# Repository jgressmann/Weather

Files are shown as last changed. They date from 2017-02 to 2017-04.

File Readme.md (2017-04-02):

# Weatherbug

A project to log temperature and relative humidity from battery powered sensor devices via radio.

## Overview

There are two parts to this project, a [Raspberry Pi](https://www.raspberrypi.org/) (RPI) which listens for sensor data and one or multiple sensor devices (henceforth simply called sensor or device).

The devices periodically send their sensor readings to the RPI by means of Nordic's [nRF24L01+](http://www.nordicsemi.com/eng/Products/2.4GHz-RF/nRF24L01) 2.4GHz radio (abbrev. to RF24 hereafter). Upon reception the sensor data is logged to file on the RPI.

### Mode of Operation

When a sensor device is first powered up it monitors the radio for a clock source. A clock source can be either the RPI which provides the master clock or another, properly synced, sensor device.

Once the device detects the clock it goes to sleep until the next _send_ interval. When the time comes the device is wakes up, takes an enviromental reading, and transmits the result to the RPI. At the end of this short _send period_ the sensor goes back to sleep.

### Network Topology

The sensor devices and the RPI form a mesh network. Routing in the network is done using the [B.A.T.M.A.N. protocol](https://tools.ietf.org/html/draft-wunderlich-openmesh-manet-routing-00). Sensor data is sent using a stripped down version of [TCP](https://tools.ietf.org/html/rfc793).

### Power supply and power consumption

Given the sensor device is designed to run on batteries it has to be operated on D.C. current with a max. input voltage of 6V. I have seen the device work correctly with input voltages as low as 3.5V.

Typical power consumption is around 25uA when the device is asleep and 15mA when active.

Under optimal conditions, the sensor can function on the battery for more than a year. However, failure to sync the device clock to the master clock cause it to enter a power consuming monitoring state. If this state persists AAA batteries are typically drained within days.

## Hardware

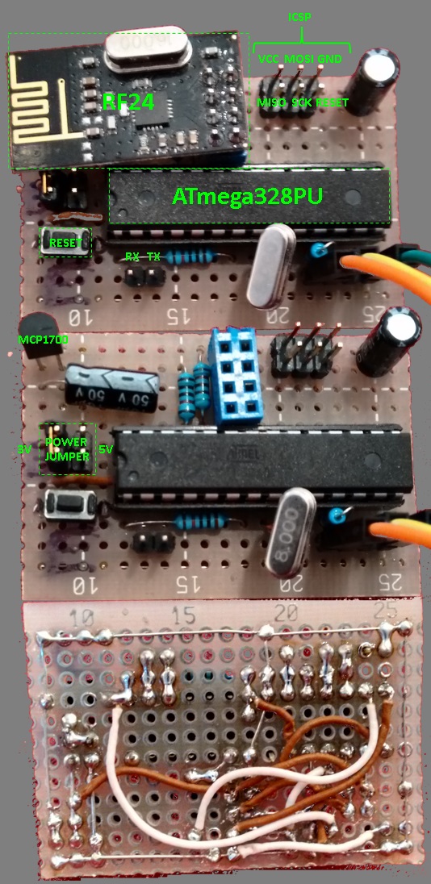
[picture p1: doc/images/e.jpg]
images of one of my devices


You will need to build the sensor devices. The parts are approx. EUR 10 per device. The circuit diagram is [here](doc/Weatherbug r1.2.fzz). I used the free and very nice [Frizzing](http://fritzing.org/) tool for the layout.

You'll also need to solder a capacitor to an RF24 radio chip and connect it to the RPI. Otherwise the radio will most likely not work due to power fluctuations. I use a 1uF capacitor which seems to do the trick.

Other than the device parts and some soldering skills you will need

* An avrdude compatible AVR programmer like [usbasp](http://www.fischl.de/usbasp/)
* a serial/COM port or an USB to serial adaptor to connect to the device UART
* a terminal program to communicate over the serial connection (I use picocom)

## Software

To build the device firmware you will need

* an Atmel (AVR) toolchain (libc, gcc, binutils) to build the firmware
* avrdude to upload the device firmware
* cmake 3.0 or better

If your are on Debian Linux

```
$ sudo apt-get install avrdude avr-libc gcc-avr binutils-avr
```

should get you set up.

### Building the device software

Get the sources, then run `cmake` on `src/avr/weatherbug` to configure the build environment. Next, run `make` (or whatever tool the cmake generated build instructions for) to build the firmware. Once the firmware image has been built, you can upload it to the device using `make flash_1.2` (assuming you use an usbasp compatible AVR programmer). Otherwise you will need to call `avrdude` with the right parameters for your device.

### Building the RPI software

Run `cmake` on `src/rpi` to set up the build, then run `make` followed by  `sudo DESTDIR=/path/to/install/to make install` to install the binaries

## Configuring the sensor device

Connect a power source to the device and hook up your serial cables. Make sure to connect the mass pin of the serial cable to the mass pin of the device, else you run danger of having a floating potential which might kill the device.

Also note that the serial communication will exhibit seemingly strange behavior or will simply cease to function if the cables are too long. I have worked with up to 30 cm, but as usual your mileage may vary.

The device is configured to 38400 baud with 8 data bits, 1 stop bit and no parity (8N1). Initiate a connection to the device using your favorite terminal program, e.g.

```
$ picocom -c -b 38400 --imap lfcrlf /dev/ttyUSB0
```

Once connected, hit the reset button. You should see the device greeting in the terminal program

```
Hello there!
This is Weatherbug version .....
```

### Service mode

During the first 10 seconds after power on or reset, the device is in bootstrap mode and will accept commands via the terminal. Type `?`+ENTER (the ? character followed by the ENTER key) to see a list of commands. Switch the device to service mode by typing `!serv`+ENTER.

Once in service mode you can configure the device using the various `!` commands. Type `?`+ENTER to see what's available.

Most settings are applied immediately and are not persisted so you can play around with them to try things out. If you muck up, simply reset the device and it will be back to its original configuration. To save your changes type `!cfst`+ENTER at the prompt.

When you are finished, type `!dflt`+ENTER to return to default mode.

#### Configuration caveats

1. The RF24 setup must be the _same_ for all devices _and_ the RPI in order to communicate via radio. Specifically
 * radio channel (defaults to 76)
 * CRC selection (defaults to 16 bit)
 * data rate (defaults to 2MBit)

 must be identical.

1. The payload size must be set to 32 bytes and the CRC to 16 bit on the RPI. These are the default settings for `rf24-packet-router` so everything _should_ work out of the box.

1. Each device as well as the RPI must have a _unique_ network id.

1. The network id `0xff` is reserved as the broadcast address.

## Start the monitoring software on the RPI

Start the packet router that will listen on the RF24 device

```
$ sudo rf24-packet-router --sleep 100 &
```

Then start the network which will handle the master clock generation, routing, and TCP.

```
$ rf24-network -i <network id> &
```

And finally start

```
$ rf24-tcp | tee sensor.log
```

to dump TCP messages to console and file.

## Troubleshooting

Let's face it. Things don't always work perfectly. For radio related issues there are two helper programs available to track down communication issues.

`rf24-ping` continously sends ping messages to the broadcast address.
`rf24-echo` prints whatever it receives to stdout/USART0.

## License

This software and documentation is available under the [MIT license](https://opensource.org/licenses/MIT)

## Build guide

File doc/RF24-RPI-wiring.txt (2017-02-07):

yellow RPI pin 26 CE
orange RPI pin 24 CSN
red    RPI pin 23 SCLK
black  RPI pin 21 MISO
brown  RPI pin 19 MOSI
gray   RPI pin 20 GND
white  RPI pin 17 3V3
       RPI pin 22 IRQ

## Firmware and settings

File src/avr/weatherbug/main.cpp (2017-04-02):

#include <avr/interrupt.h>
#include <avr/io.h>
#include <avr/eeprom.h>
#include <avr/power.h>
#include <avr/sleep.h>
#include <avr/pgmspace.h>
#include <avr/cpufunc.h>
#include <avr/signature.h>
#include <util/delay.h>
#include <util/atomic.h>

#include <stdio.h>
#include <string.h>
#include <stdlib.h>
#include <ctype.h>


#include "Watchdog.h"
#include "Timer.h"
#include "../../Misc.h"
#include "../Debug.h"
#include "../USART0.h"

#include "../SPI.h"
#include "../RF24.h"


#include "../../Batman.h"
#include "../../Network.h"
#include "../../Time.h"
#include "../../TCP.h"
#include "../DHT.h"

//#define ACTIVE_SLEEP
#define WATCHDOG_SLEEP
//#define TIMER2_SLEEP

#define TICKS_PER_MS (F_CPU/1000L)
#define TICKS_PER_US (F_CPU/1000000L)
// Atmel doc, p. 40
#define BOD_STARTUP_PENALTY_US 60


// Depends on fuses and if int. osc. or crystal, here we assume
// a full swing crystal thus 16K ticks
#define WDT_STARTUP_PENALTY_TICKS (UINT16_C(1)<<14)
#define WDT_STARTUP_PENALTY_MS (WDT_STARTUP_PENALTY_TICKS/TICKS_PER_MS)


#define NAME "Weatherbug"
#define VERSION_MAJOR 2
#define VERSION_MINOR 6
#define VERSION_PATCH 0
#define NODE_NAME_BUFFER_LENGTH 7
#define NODE_NAME_BUFFER_SIZE (NODE_NAME_BUFFER_LENGTH + 1)
static const char s_VersionString_P[] PROGMEM = NAME " " STRINGIFY(VERSION_MAJOR) "." STRINGIFY(VERSION_MINOR) "." STRINGIFY(VERSION_PATCH);
static const char Network_Address_Format_P[] PROGMEM = "%#02x\n";

/******************************************************************************/
/* Forward declerations                                                       */
/******************************************************************************/

#ifndef NDEBUG
extern "C" {
FILE* s_FILE_Debug NOINIT;
}
#endif

static void RF24_Init();
static uint16_t BATV_Read();
static inline uint16_t BATV_ToMilliVolt(uint16_t counts);

enum {
    MODE_STATE_UNINITIALIZED = -1,
    MODE_STATE_INITIAL = 0,
    MODE_STATE_SERVICE = 1,
    MODE_STATE_DEFAULT = 2,
};


struct ModeContext {
    uint32_t StartOfInterval;
    DHT_Context DHTContext;
    uint16_t Iterations;
    uint8_t USART0Index;
    int8_t CurrentState;
    uint8_t TargetState         : 2;
    uint8_t Enter               : 1;
    uint8_t Interval            : 1;
    uint8_t FeaturesReleased    : 1;
    uint8_t Run                 : 1;
    uint8_t DHTTries;
    uint8_t Temperature;
    uint8_t Humidity;
    char USART0Buffer[32];
};

static ModeContext s_ModeContext NOINIT;

#ifdef WATCHDOG_SLEEP
typedef struct {
    uint16_t CalibrationFactor;
    uint8_t Expired     : 1;
    uint8_t Calibrate   : 1;
} WatchdogData;

static volatile WatchdogData s_WATCH NOINIT;

#define WATCH_RequestCalibration() \
    s_WATCH.Calibrate = 1

#endif


/******************************************************************************/
/* Features (FEAT)                                                            */
/*                                                                            */
/* Reference counted access to device features:                               */
/* - USART0                                                                   */
/* - RF24                                                                     */
/******************************************************************************/
#define FEAT_USART0     0
#define FEAT_RF24       1

static volatile uint8_t s_Features[2] NOINIT;

static
inline
void
FEAT_Init() {
    memset((void*)s_Features, 0, sizeof(s_Features));
}

static
void
FEAT_Acquire(uint8_t features) {
    //Commented by the virtue that all code paths using it
    // top-level assert that interrupts are off
    //ASSERT_INTERRUPTS_OFF(return, "main");
    if (features & _BV(FEAT_USART0)) {
//        DEBUG_P("USART0 %d\n", s_Features[FEAT_USART0]);
        if (0 == s_Features[FEAT_USART0]++) {
            power_usart0_enable();
            USART0_Init();
            DEBUG_P("USART0 started\n");
        }
    }

    if ((features & _BV(FEAT_RF24))) {
//        DEBUG_P("RF24 %d\n", s_Features[FEAT_RF24]);
        if (0 == s_Features[FEAT_RF24]++) {
            power_spi_enable();

            RF24_PowerUp();

            // set CE
            PORTB |= _BV(PB1);
            DEBUG_P("RF24 started\n");
        }
    }
}

static
void
FEAT_Release(uint8_t features) {
    //ASSERT_INTERRUPTS_OFF(return, "main");
    if (features & _BV(FEAT_USART0)) {
        if (--s_Features[FEAT_USART0] == 0) {
            DEBUG_P("USART0 stopped\n");
            USART0_SendFlush();
            USART0_Uninit();
            power_usart0_disable();
        }
    }

    if ((features & _BV(FEAT_RF24))) {
        if (--s_Features[FEAT_RF24] == 0) {
            DEBUG_P("RF24 stopped\n");

            // clear CE line
            PORTB &= ~_BV(PB1);

            RF24_PowerDown();
            RF24_FlushRx();
            RF24_FlushTx();
            RF24_UpdateRegister(RF24_REG_STATUS, RF24_STATUS_MAX_RT | RF24_STATUS_TX_DS | RF24_STATUS_RX_DR, RF24_STATUS_MAX_RT | RF24_STATUS_TX_DS | RF24_STATUS_RX_DR);
            RF24_TxQueueClear();

            // this sequence appears to reliably make the power
            // comsumption for r.1.2 drop from 100uA to ~25uA
            RF24_PowerUp();
            _delay_ms(5);
            RF24_PowerDown();

            power_spi_disable();
        }
    }
}

static
inline
int8_t
FEAT_Available(uint8_t features) {
//    ASSERT_INTERRUPTS_OFF(return, "main");
    if ((features & _BV(FEAT_USART0)) && !s_Features[FEAT_USART0]) {
        return 0;
    }

    if ((features & _BV(FEAT_RF24)) && !s_Features[FEAT_RF24]) {
        return 0;
    }

    return 1;
}


/******************************************************************************/
/* Timed work queue (WORK)                                                    */
/*                                                                            */
/* Clients can register for callbacks at a given time int the future.         */
/******************************************************************************/
typedef void (*WorkCallback)(void* ctx);
typedef struct _Work_Item {
    uint32_t TimeTillUpdate;
    WorkCallback Callback;
    void* Ctx;
} Work_Item;
volatile uint8_t s_Work_ItemCount NOINIT;
Work_Item s_Work_Items[8] NOINIT;

static
inline
void
WORK_Add(void* ctx, WorkCallback callback) {
    ASSERT_FILE(s_Work_ItemCount < _countof(s_Work_Items), return, "main");
    s_Work_Items[s_Work_ItemCount].Callback = callback;
    s_Work_Items[s_Work_ItemCount].Ctx = ctx;
    s_Work_Items[s_Work_ItemCount].TimeTillUpdate = 0;
    ++s_Work_ItemCount;
//    DEBUG_P("Work: %" PRIu32 " add %d\n", Time_Now(), s_Work_ItemCount);
}

#define WORK_AddEx(ctx, callback) \
    do { \
        /*DEBUG_P(STRINGIFY(callback) "\n"); */ \
        WORK_Add(ctx, callback); \
    } while (0)


static
void
WORK_Remove(WorkCallback callback) {
//    DEBUG_P("Work: %" PRIu32 " remove %d ", Time_Now(), s_Work_ItemCount);
    for (uint8_t i = s_Work_ItemCount - 1; i < s_Work_ItemCount; --i) {
        if (s_Work_Items[i].Callback == callback) {
            s_Work_Items[i] = s_Work_Items[--s_Work_ItemCount];
            return;
        }
    }

//    ASSERT_FILE(0, "main");
//    DEBUG_P("%d\n", s_Work_ItemCount);
}

static
void
WORK_Update(uint32_t elapsed) {
    ASSERT_INTERRUPTS_OFF(return, "main");
    for (uint8_t i = s_Work_ItemCount - 1; i < s_Work_ItemCount; --i) {
        if (s_Work_Items[i].TimeTillUpdate <= elapsed) {
            s_Work_Items[i].TimeTillUpdate = 0;
//            DEBUG_P("Work: %" PRIu32 " idx %d\n", Time_Now(), i);
            s_Work_Items[i].Callback(s_Work_Items[i].Ctx);
        } else {
            s_Work_Items[i].TimeTillUpdate -= elapsed;
//            DEBUG_P("Work: %" PRIu32 " idx %d: %" PRIu32 "\n", Time_Now(), i, s_Work_Items[i].TimeTillUpdate);
        }
    }
}

static
void
WORK_RequestUpdate(WorkCallback callback, uint32_t time) {
    //DEBUG("Work: update %p %" PRIu32 "\n", callback, time);
    for (uint8_t i = 0; i < s_Work_ItemCount; ++i) {
        if (s_Work_Items[i].Callback == callback) {
            s_Work_Items[i].TimeTillUpdate = time;
            break;
        }
    }
}

static
uint32_t
WORK_NextUpdate() {
    //DEBUG("Work: %u\n", s_Work_Callback_Count);
    uint32_t next = ~UINT32_C(0);
    for (uint8_t i = 0; i < s_Work_ItemCount; ++i) {
        if (s_Work_Items[i].TimeTillUpdate < next) {
            next = s_Work_Items[i].TimeTillUpdate;
        }
    }

    return next;
}

static
inline
void
WORK_Init() {
    s_Work_ItemCount = 0;
}

/*******************************************************************************
 * Sensor correction (CORR)
 ******************************************************************************/


typedef struct _Curve {
    int8_t* eep_values;
    int8_t* eep_offsets;
    const uint8_t size;
} Curve;

#define CORR_Instance(name, values, offsets, size) \
    static Curve name = { values, offsets, size }

static
void
CORR_Reset(Curve* c) {
    for (uint8_t i = 0; i < c->size; ++i) { \
        eeprom_write_byte((uint8_t*)&c->eep_values[i], 0xff);
    }
}

//static
//void
//CORR_Set(Curve* c, int8_t v, int8_t o) {
//    uint8_t index = 0;
//    uint8_t move = 1;
//    for (uint8_t i = 0; i < c->size; ++i) {
//        int8_t candidate = eeprom_read_byte((uint8_t*)&c->eep_values[i]);
//        if (candidate == (int8_t)0xff || candidate == v) {
//            move = 0;
//            break;
//        }

//        if (candidate > v) {
//            break;
//        }

//        ++index;
//    }

//    DEBUG_P("index=%u\n", index);

//    if (index < c->size && move) { // move away
//        for (uint8_t i = c->size - 1; i > index; --i) {
//            DEBUG_P("move %u back\n", i-1);
//            uint8_t vp = eeprom_read_byte((uint8_t*)&c->eep_values[i-1]);
//            uint8_t op = eeprom_read_byte((uint8_t*)&c->eep_offsets[i-1]);
//            eeprom_write_byte((uint8_t*)&c->eep_values[i], vp);
//            eeprom_write_byte((uint8_t*)&c->eep_offsets[i], op);
//        }
//    }

//    eeprom_write_byte((uint8_t*)&c->eep_values[index], v);
//    eeprom_write_byte((uint8_t*)&c->eep_offsets[index], o);
//}

static
inline
void
CORR_Set(Curve* c, uint8_t index, int8_t v, int8_t o) {
//    ASSERT_FILE(c, return, "main");
//    ASSERT_FILE(index < c->size, return, "main");

    eeprom_write_byte((uint8_t*)&c->eep_values[index], v);
    eeprom_write_byte((uint8_t*)&c->eep_offsets[index], o);
}

static
inline
void
CORR_Get(const Curve* c, uint8_t index, int8_t* v, int8_t* o) {
    //    ASSERT_FILE(c, return, "main");
    //    ASSERT_FILE(index < c->size, return, "main");
    *v = eeprom_read_byte((uint8_t*)&c->eep_values[index]);
    *o = eeprom_read_byte((uint8_t*)&c->eep_offsets[index]);
}

static
int8_t
CORR_Extrapolate(const Curve* c, int8_t v, uint8_t loIndex, uint8_t hiIndex) {
    int8_t vl = eeprom_read_byte((uint8_t*)&c->eep_values[loIndex]);
    int8_t vh = eeprom_read_byte((uint8_t*)&c->eep_values[hiIndex]);
    int8_t yl = eeprom_read_byte((uint8_t*)&c->eep_offsets[loIndex]);
    yl += vl;
    int8_t yh = eeprom_read_byte((uint8_t*)&c->eep_offsets[hiIndex]);
    yh += vh;
    DEBUG_P("vl=%d, vh=%d\n", vl, vh);
    DEBUG_P("yl=%d, yh=%d\n", yl, yh);
    int16_t m = ((yh - yl) * INT16_C(256)) / (vh-vl);
    int8_t b = yl - (m * vl) / INT16_C(256);
    DEBUG_P("m=%d, b=%d\n", m, b);
    //v += (m * (v - vh)) / INT16_C(256) + b;
    return (m * v) / INT16_C(256) + b;
}
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
int
main() {
    // interrupts off
    cli();

    // turn off stuff we absolutely don't use
    //power_ada_disable();
    //power_usb_disable();
    //power_rtc_enable();
    //power_adca_disable();
    //power_evsys_disable();


    power_twi_disable();
    power_timer0_disable();
//    power_timer1_disable();
#ifndef TIMER2_SLEEP
    power_timer2_disable();
#endif
    DHT_Uninit();

    Network_SetSendCallback(NetworkSendCallback);

#ifdef WATCHDOG_SLEEP
    WDT_SetCallback(WATCH_MainLoopCallback);
#endif

    FEAT_Init();
    WORK_Init();

    BATV_Init();
    USART0_Init();
    s_FILE_USART0 = fdevopen(USART0_PutChar, USART0_GetChar);
#ifndef NDEBUG
    stderr = s_FILE_Debug = s_FILE_USART0;
#endif



//    {
//        char buf[32];
//        snprintf(buf, sizeof(buf), "MCUSR %02x\n", s_Mcusr);
//        USART0_SendString(buf);
//    }

    if (s_Mcusr & _BV(PORF)) {
        const char* message = PSTR("Power-on reset.\n");
        USART0_SendString_P(message);
    }
    if (s_Mcusr & _BV(EXTRF)) {
        const char* message = PSTR("External reset!\n");
        USART0_SendString_P(message);
    }
    if (s_Mcusr & _BV(BORF)) {
        const char* message = PSTR("Brownout reset!\n");
        USART0_SendString_P(message);
    }
    if (s_Mcusr & _BV(WDRF)) {
        const char* message = PSTR("Watchdog reset!\n");
        USART0_SendString_P(message);
    }
   // if (mcucsr & (1<<JTRF )) DEBUG(("JTAG reset!\n");

    {
        fprintf_P(s_FILE_USART0, PSTR("Hello there!\nThis is "));
        fprintf_P(s_FILE_USART0, s_VersionString_P);
        putc('\n', s_FILE_USART0);
        fprintf_P(s_FILE_USART0, PSTR("Copyright (c) 2016, 2017 Jean Gressmann <jean@0x42.de>"));
        putc('\n', s_FILE_USART0);
        putc('\n', s_FILE_USART0);
    }
    {
        uint16_t confInitialized =  eeprom_read_word(&s_EEP_Initialized);
        if (confInitialized != INITIALIZED_SIGNATURE) {
            const char* str = PSTR("No configuration found in EEPROM. Activating default configuration.\n");
            USART0_SendString_P(str);
            CONF_ActivateDefault();
            CONF_Store();
        } else {
            CONF_Load();
            const char* str = PSTR("Configuration loaded.\n");
            USART0_SendString_P(str);
        }
    }

    RF24_Init();
    RF24_SetMessageReceivedCallback(RF24_MessageReceivedHandler);

    DEBUG_P("RF24 stopped\n");
    RF24_PowerDown();
    power_spi_disable();
    DEBUG_P("USART0 stopped\n");
    USART0_SendFlush();
    USART0_Uninit();
    power_usart0_disable();

#ifndef NDEBUG
    FEAT_Acquire(_BV(FEAT_USART0));
#endif

#if defined(WATCHDOG_SLEEP)
    set_sleep_mode(SLEEP_MODE_PWR_DOWN);
    WATCH_Calibrate();
#elif defined(TIMER2_SLEEP)
    set_sleep_mode(SLEEP_MODE_PWR_SAVE);
    TIMSK2 = 0b00000010; // A output compare match
#endif


    SyncTimeContext syncTimeContext;
    memset(&syncTimeContext, 0, sizeof(syncTimeContext));
    WORK_Add(&syncTimeContext, SyncTime);

    memset(&s_ModeContext, 0, sizeof(s_ModeContext));
    s_ModeContext.CurrentState = MODE_STATE_UNINITIALIZED;
    WORK_Add(&s_ModeContext, ProcessMode);

    uint32_t sleepStart = Time_Now();

    CLK_Start();

    for ever {
        const uint32_t sleepEnd = Time_Now();
        const uint32_t elapsed = sleepEnd - sleepStart;
        sleepStart = sleepEnd;

        WORK_Update(elapsed);

        const uint32_t sleep = WORK_NextUpdate();
        if (sleep) {
            //DEBUG_P("Sleep: %" PRIu32 "\n", sleep);

#if defined(ACTIVE_SLEEP)
            const uint16_t SleepStep = 128;
            if (sleep >= SleepStep) {
                //                    DEBUG("Z");
                CLK_ClaimTimer(0);
                _delay_ms(SleepStep);
                CLK_StartTimer();
                uint16_t eplased = SleepStep + CLK_ClaimMillis();
                Time_Update(eplased);
                RF24_PollEx();
            } else {
                for (uint8_t i = 0; i < sleep; ++i) {
                    //                        DEBUG("z");
                    SleepOneMillisecond();
                    CLK_ClaimTimer(1);
                    uint16_t eplased = CLK_ClaimMillis();
                    if (eplased) {
                        Time_Update(eplased);
                    }
                }
            }

            //DEBUG("Sleep done\n");

#elif defined(WATCHDOG_SLEEP)
            uint16_t passed;
            uint16_t millisecondsToSleep = sleep > WATCH_MAX_SLEEP_MS ? WATCH_MAX_SLEEP_MS : sleep;
            if (millisecondsToSleep < 16 + WDT_STARTUP_PENALTY_MS) {
                passed = 0;
                while (millisecondsToSleep--) {
                    SleepOneMillisecond();
                    CLK_ClaimTimer(1);
                }
            } else {
                uint8_t prescaler = 9;
                uint16_t millis = WATCH_MAX_SLEEP_MS;
                while (millis > millisecondsToSleep) {
                    --prescaler;
                    millis >>= 1;
                }

                // Turn off the clock but leave timer1 enabled.
                // The timer will be used to measure the error of the watchdog
                CLK_ClaimTimer(0);

                passed = 0;
                if (s_WATCH.Calibrate) {
                    passed += WATCH_CALIBRATION_DURATION_MS;
                    WATCH_Calibrate();
                }

#ifndef NDEBUG
                USART0_SendFlush();
#endif

                // turn off timer to save power
                power_timer1_disable();

                WATCH_ResetExpired();
                WDT_On(0, 1, prescaler);

                sleep_enable();
                sleep_bod_disable();
                sei();
                sleep_cpu();
                cli();
                sleep_disable();

                if (WATCH_IsExpired()) {
                    uint16_t corrected = WATCH_CorrectTime(millis);
                    DEBUG_P("Slept for %u, corrected %u\n", millis, corrected);
                    passed += corrected;
                } else { // woke up before WDT timeout
                    WDT_Off();
                    // This can't be zero else we might end up never making any
                    // progress with WORK due to continous interrupts
                    passed += millis / 2;
                    DEBUG_P("Int\n");
                }

                CLK_AddTicks(WDT_STARTUP_PENALTY_TICKS);

                // enable timer1 and start the clock
                power_timer1_enable();
                CLK_Start();
            }

            passed += CLK_ClaimMillis();

            if (passed) {
                Time_Update(passed);
            }
#else

//            if (sleep <= 8) {
//                for (uint8_t i = 0; i < sleep; ++i) {
//                    _delay_ms(1);
//                }
//                CLK_ClaimTimer(1);
//                uint16_t eplased = CLK_ClaimMillis();
//                Time_Update(eplased);
//            } else {
#if F_CPU >= 1600000L
#   define TIMER2_MAX_SLEEP 16
#else
#   define TIMER2_MAX_SLEEP 32
#endif
                uint16_t millis = sleep;
                if (millis > TIMER2_MAX_SLEEP) {
                    millis = TIMER2_MAX_SLEEP;
                }
                uint32_t ticks = millis * TICKS_PER_MS;
//                if (ticks > 0xfff) {
//                    ticks = 0xfff;
//                }


                uint16_t count, elapsed;
                uint8_t prescaler;
                uint8_t shift;
                if (ticks >= 1024) {
                    prescaler = 7;
                    count = ticks / 1024;
                    shift = 10;
                } else if (ticks >= 256) {
                    prescaler = 6;
                    count = ticks / 256;
                    shift = 8;
                } else if (ticks >= 128) {
                    prescaler = 5;
                    count = ticks / 128;
                    shift = 7;
                }  else if (ticks >= 64) {
                    prescaler = 4;
                    count = ticks / 64;
                    shift = 6;
                }  else if (ticks >= 32) {
                    prescaler = 3;
                    count = ticks / 32;
                    shift = 5;
                }  else if (ticks >= 8) {
                    prescaler = 2;
                    count = ticks / 8;
                    shift = 3;
                } else {
                    prescaler = 1;
                    count = ticks;
                    shift = 0;
                }
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

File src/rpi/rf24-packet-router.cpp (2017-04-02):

/* The MIT License (MIT)
 *
 * Copyright (c) 2016, 2017 Jean Gressmann <jean@0x42.de>
 *
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
 * THE SOFTWARE IS PROVIDED "AS IS", WITHOUT WARRANTY OF ANY KIND, EXPRESS OR
 * IMPLIED, INCLUDING BUT NOT LIMITED TO THE WARRANTIES OF MERCHANTABILITY,
 * FITNESS FOR A PARTICULAR PURPOSE AND NONINFRINGEMENT. IN NO EVENT SHALL THE
 * AUTHORS OR COPYRIGHT HOLDERS BE LIABLE FOR ANY CLAIM, DAMAGES OR OTHER
 * LIABILITY, WHETHER IN AN ACTION OF CONTRACT, TORT OR OTHERWISE, ARISING FROM,
 * OUT OF OR IN CONNECTION WITH THE SOFTWARE OR THE USE OR OTHER DEALINGS IN
 * THE SOFTWARE.
 */

#include <sys/types.h>
#include <sys/stat.h>
#include <sys/epoll.h>
#include <sys/socket.h>
#include <sys/timerfd.h>
#include <sys/un.h>
#include <unistd.h>
#include <fcntl.h>
#include <signal.h>
#include <semaphore.h>
#include <pthread.h>
#include <errno.h>

#include <algorithm>
#include <assert.h>
#include <stdlib.h>
#include <errno.h>
#include <string.h>
#include <stdint.h>
#include <toe/cmdlopt.h>
#include <toe/buffer.h>
#include <linuxapi/linuxapi.h>
#include <RF24/RF24.h>

#include "Globals.h"


#define NUMBER_OF_READ_PIPES 6
#define MAX_PAYLOAD_SIZE 32

#define STRINGIFY1(x) #x
#define STRINGIFY(x) STRINGIFY1(x)
#define ERROR(...) fprintf(stderr, "ERROR: " __VA_ARGS__)
#define LOG(...) fprintf(stdout, __VA_ARGS__)

#if 1
#   define DEBUG(...) fprintf(stderr, __VA_ARGS__)
#else
#   define DEBUG(...)
#endif


static buffer* s_Connections;
#define int_begin(buf) ((int*)buf->beg)
#define int_end(buf) ((int*)buf->end)
#define int_reserve(buf, count) buf_resize(buf, count*sizeof(int))
#define int_pop_back(buf) buf->end -= sizeof(int)
#define int_used(buf) (buf_used(buf)/sizeof(int))



static void EPollAcceptHandler(void* ctx, epoll_event* ev);
static void EPollConnectionDataHandler(void* ctx, epoll_event* ev);
static void EPollTimerHandler(void *ctx, epoll_event *ev);
static void EPollIrqPinHandler(void *ctx, epoll_event *ev);
static void PollRadio();


static sem_t s_Shutdown;

static
void
Shutdown() {
    sem_post(&s_Shutdown);
}

static
void
SignalHandler(int) {
    Shutdown();
}


template<typename T>
static
int
UnsignedParser(const char* arg, T& value) {
    char* end = NULL;
    value = (T)strtoul(arg, &end, 10);
    if (!end || end == arg) {
        ERROR("Argument '%s' could not be converted to unsigned int\n", arg);
        return -1;
    }

    return 0;
}

static
inline
int ByteParser(const char* arg, uint8_t& value) {
    return UnsignedParser(arg, value);
}

static uint8_t s_Channel = 76;
static
int
Channel_Parser(void*, char* arg) {
    return ByteParser(arg, s_Channel);
}


static bool s_Dump = false;
static
int
Dump_Parser(void*, char* arg) {
    s_Dump = true;
    return 0;
}

static uint8_t s_Read_Pipes[NUMBER_OF_READ_PIPES] = { 1, 2, 3, 4, 5, 6 };
static
int
Read_Pipe_Parser(void*, char* arg) {
    char* result;
    char* end;
    int index = 0;
    while ((result = strtok_r(arg, ";, \t", &end)) != NULL && index < NUMBER_OF_READ_PIPES) {
        arg = NULL;
        int error = ByteParser(result, s_Read_Pipes[index]);
        if (error) {
            ERROR("Pipe index %d\n", index);
            return error;
        }
        ++index;
    }
    return 0;
}

static uint8_t s_WriteId = 1;
static
int
Write_Pipe_Parser(void*, char* arg) {
    return ByteParser(arg, s_WriteId);
}


static const cmdlopt_arg s_Dummy_Arg[] = {
    CMDLOPT_ARGUMENT_TERMINATOR
};

static const cmdlopt_arg s_BaseAddress_Arg[] = {
    { "hex string", "the most signficant 4 bytes of the pipe address", "0xdeadbeef" },
    CMDLOPT_ARGUMENT_TERMINATOR
};
static uint32_t s_BaseAddress = 0xdeadbeef;
static
int
Base_Address_Parser(void*, char* arg) {
    int error = 0;
    if (arg && *arg) {
        // strip off 0(x|X) prefix if present
        if (arg[0] == '0' && (arg[1] == 'x' || arg[1] == 'X')) {
            arg += 2;
        }
        char* end = NULL;
        s_BaseAddress = strtoul(arg, &end, 16);
        if (!end || end == arg) {
            error = -1;
        }
    } else {
        error = -1;
    }

    if (error) {
        ERROR("Argument %s is not a valid hex value\n", arg);
    }

    return error;
}

static const cmdlopt_arg s_Data_Rate_Arg[] = {
    { "0", "250KBPS (plus modesls only)", NULL },
    { "1", "1MBPS", NULL },
    { "2", "2MBPS (default)", NULL },
    CMDLOPT_ARGUMENT_TERMINATOR
};

static uint8_t s_DataRate = 2;
static const rf24_datarate_e s_DataRateTable[] = { RF24_250KBPS, RF24_1MBPS, RF24_2MBPS };
static
int
DataRate_Parser(void*, char* arg) {
    int error = ByteParser(arg, s_DataRate);
    if (!error) {
        switch (s_DataRate) {
        case 0: case 1: case 2:
            break;
        default:
            ERROR("Invalid data rate %d\n", s_DataRate);
            error = -1;
        }
    }
    return error;
}

static const cmdlopt_arg s_Power_Level_Arg[] = {
    { "0", "min", NULL },
    { "1", "low", NULL },
    { "2", "high", NULL },
    { "3", "max (default)", NULL },
    CMDLOPT_ARGUMENT_TERMINATOR
};
static uint8_t s_PowerLevel = 3;
static
int
Power_Level_Parser(void*, char* arg) {
    int error = ByteParser(arg, s_PowerLevel);
    if (!error) {
        switch (s_PowerLevel) {
        case RF24_PA_MIN:
        case RF24_PA_LOW:
        case RF24_PA_HIGH:
        case RF24_PA_MAX:
            break;
        default:
            ERROR("Invalid power level %d\n", s_PowerLevel);
            error = -1;
        }
    }
    return error;
}

static const cmdlopt_arg s_Crc_Length_Arg[] = {
    { "0", "disabled", NULL },
    { "1", "8 bits", NULL },
    { "2", "16 bits (default)", NULL },
    CMDLOPT_ARGUMENT_TERMINATOR
};
static uint8_t s_Crc_Length = 2;
static
int
Crc_Length_Parser(void*, char* arg) {
    int error = ByteParser(arg, s_Crc_Length);
    if (!error) {
        switch (s_Crc_Length) {
        case RF24_CRC_DISABLED:
        case RF24_CRC_8:
        case RF24_CRC_16:
            break;
        default:
            ERROR("Invalid CRC length %d\n", s_Crc_Length);
            error = -1;
        }
    }
    return error;
}

static uint8_t s_PayloadSize = MAX_PAYLOAD_SIZE;
static
int
Payload_Parser(void*, char* arg) {
    int error = ByteParser(arg, s_PayloadSize);
    if (!error) {
        if (!s_PayloadSize || s_PayloadSize > MAX_PAYLOAD_SIZE) {
            ERROR("Invalid payload size %d. Max payload is " STRINGIFY(MAX_PAYLOAD_SIZE) " bytes.\n", s_PayloadSize);
            error = -1;
        }
    }
    return error;
}

static uint32_t s_Sleep = 10000; // 10ms
static
int
Sleep_Parser(void*, char* arg) {
    return UnsignedParser(arg, s_Sleep);
}

static const char* s_SocketPath = RF24_PACKET_ROUTER_SOCKET_PATH;
static
int
SocketPath_Parser(void*, char* arg) {
    s_SocketPath = arg;
    return 0;
}

static uint8_t s_IrqPin = 0;
static
int
Irq_Parser(void*, char* arg) {
    return ByteParser(arg, s_IrqPin);
}
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

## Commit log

2016-02-21 Initial commit of Weatherbug project
    Weatherbug will be a device to read humidity and temperature data
    from a DHT11 sensor and relay that information via RF24 to a Raspberry
    PI which will log those values to file.
2017-01-04 Initial commit to public repo
    [Weatherbug r1.2.fzz]
2017-04-02 Attempt to fix botched merge
    [RF24.c, RF24.h]
2017-04-02 Removes arduino.cmake
